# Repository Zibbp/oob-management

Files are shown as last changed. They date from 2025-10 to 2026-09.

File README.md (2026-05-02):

# Out-of-Band Management

## Version 2

See the `v2/` directory for the second version of this project. It replaces the esp32 with a Raspberry PI Pico (rp2040) with a W5500 for Ethernet.

## Story

I do not use any enterprise servers in my homelab, instead primarly consumer parts. Rarely do any consumer or prosumer boards have OOB/IPMI except for some overpriced Asrock boards, so I have no true out-of-band management like IPMI/ILO/etc. I do have an IP-KVM which provides video, HID, and ATX power control for a *single* computer. I need this for many computers, which sent me down the rabbit hole of designing this.

I like my IP-KVM (NanoKVM, though any will work) and wanted to expand this to multiple devices. I researched HDMI KVMs to expand the number of video and HID inputs to 4. The [pikvm docs](https://docs.pikvm.org/multiport/) list a few examples for KVMs. With that information I went to AliExpress and bought the [cheapest 4-port one I could find](https://www.aliexpress.us/item/3256805792824650.html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). Smaller 2-port HDMI KVMs can switch their inputs by pulling a pin to ground. I thought this 4-port version would be the same thing, but I was incorrect. This 4-port KVM uses serial to switch inputs, this will make integration even easier.

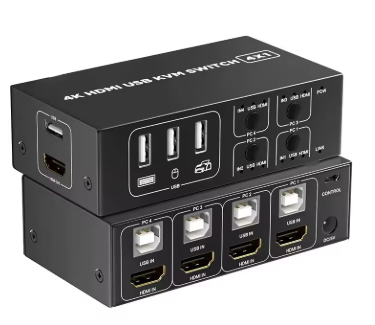
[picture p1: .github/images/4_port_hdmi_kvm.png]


My NanoKVM exposes two UART pins which works pefectly for this. By setting up a serial connection in Python and sending the following string the KVM will switch inputs.

```
G01gA // port 1
G02gA // port 2
G03gA // port 3
G04gA // port 4
```

This solves expanding HID and video to 4 device but I'm still missing power controls such as the power button, reset button, and power LED. I probably could've gotten away with using wake-on-lan packets to power on devices, but as a System Administrator having full remote power control of my servers is a necessity.

## Custom PCBs

This is my first time using KiCad and designing PCBs/schematics/components so there are likely some things wrong. It works for me and I am happy with the results.

### Bravo Board

I took inspritation from the "NanoKVM-B" board which sits inside the computer case and connects to the Motherboard pins *and* the Case wires and designed my own in KiCad. The board I call "Bravo board" sits in the computer case as well. It uses two solid state relays and one optocoupler for the power and reset button and sensing the power LED status respectively. The Bravo board uses a standard RJ45 cable to connect back to the "Alpha board".

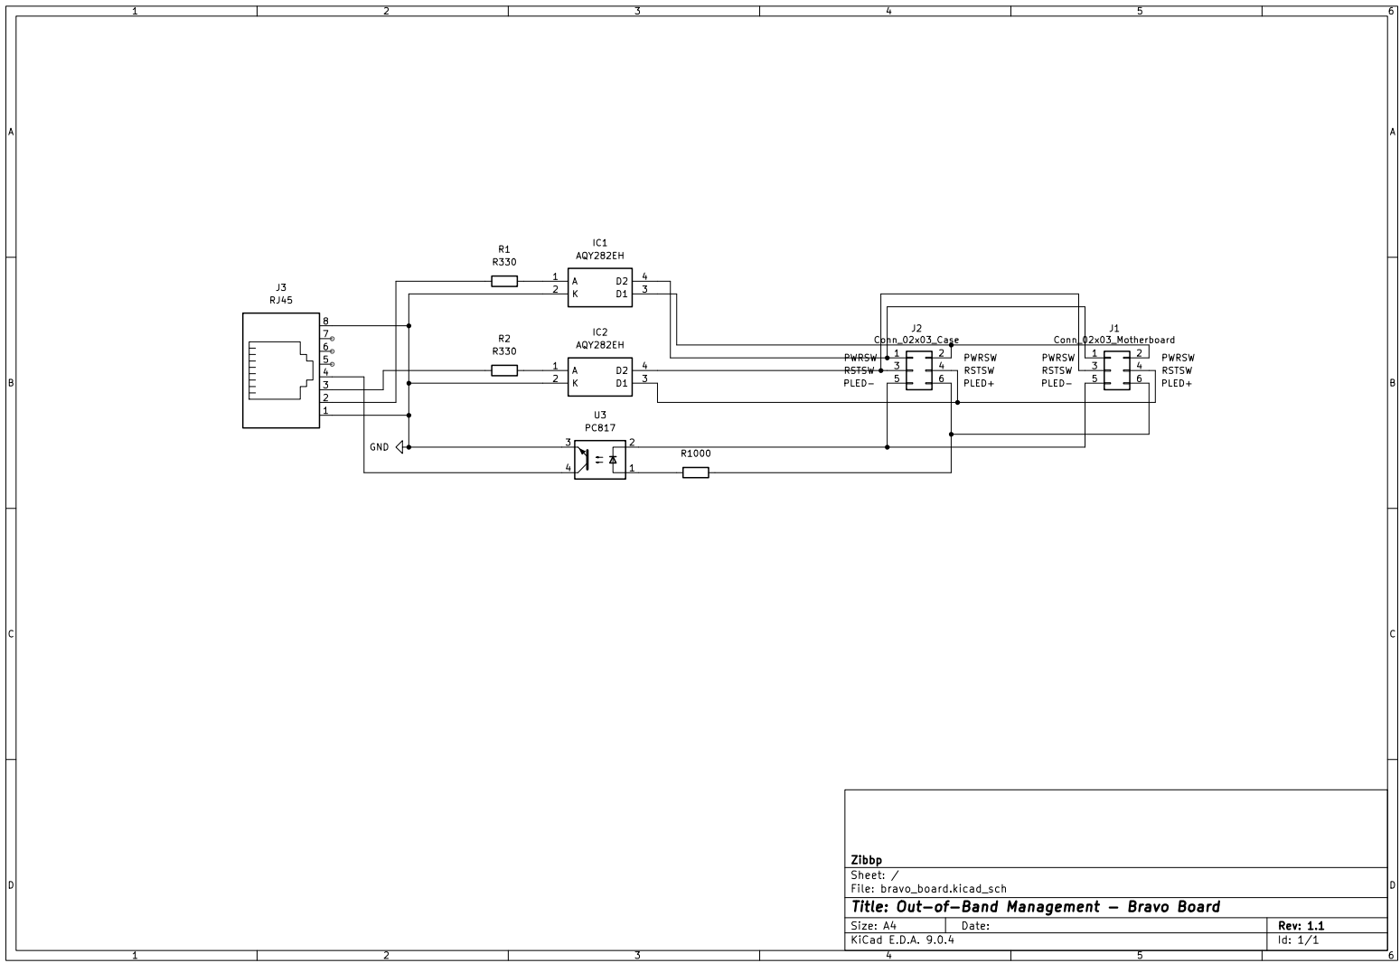
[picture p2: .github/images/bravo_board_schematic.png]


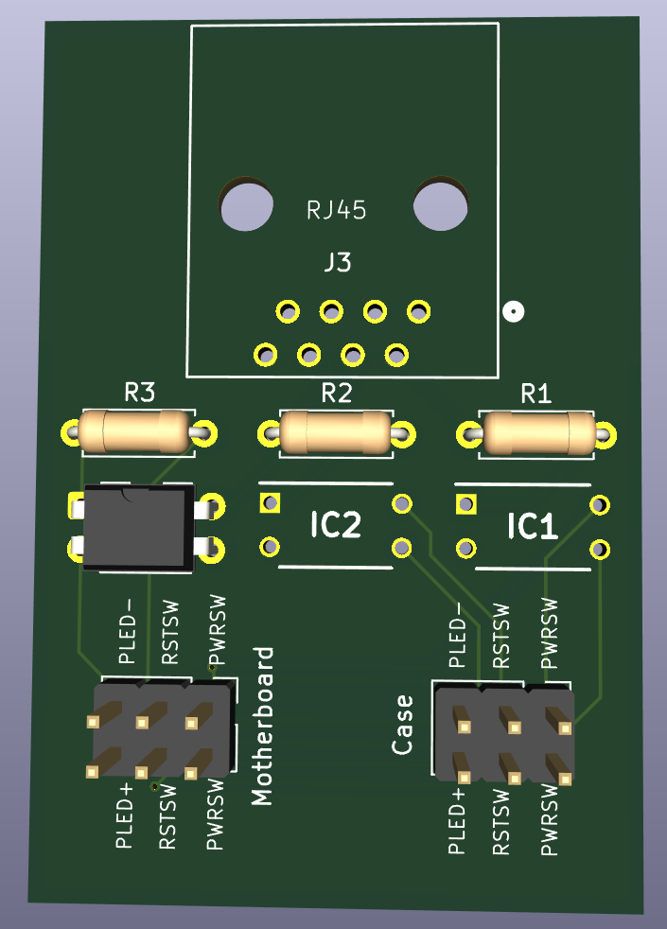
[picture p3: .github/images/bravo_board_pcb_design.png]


### Alpha Board

The "Alpha board" connects to four Bravo boards to control four computers over a standard ethernet cable. It uses a ESP32-C3 as the microcontroller and a GPIO expander. On the board are some status LEDs and two USB connectors for connecting to the HDMI-KVM (to switch video inputs) and optionally for controlling the Alpha board over a serial connection.

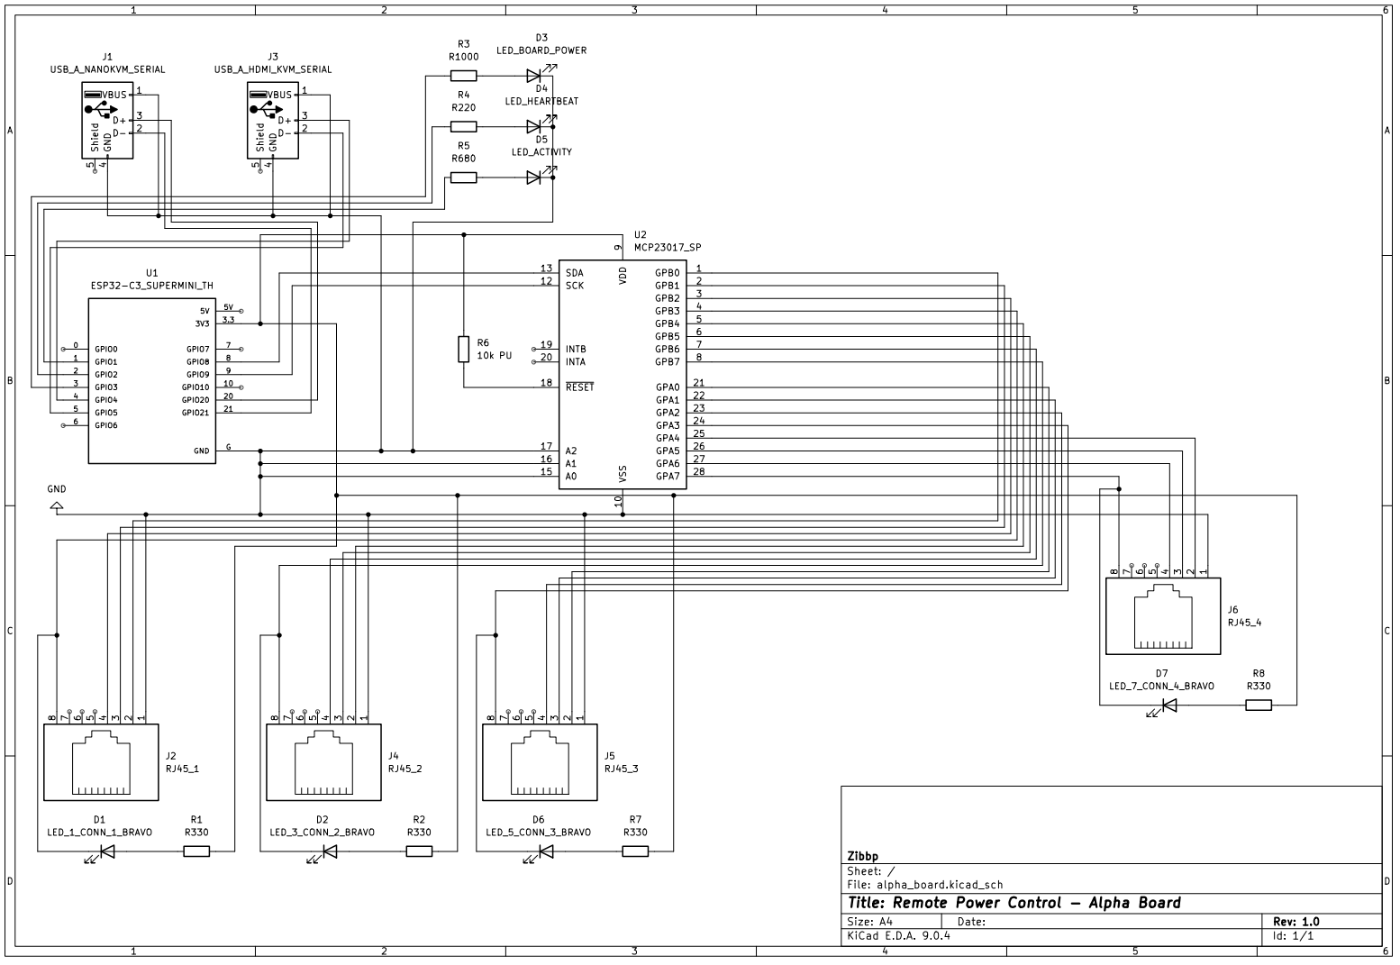
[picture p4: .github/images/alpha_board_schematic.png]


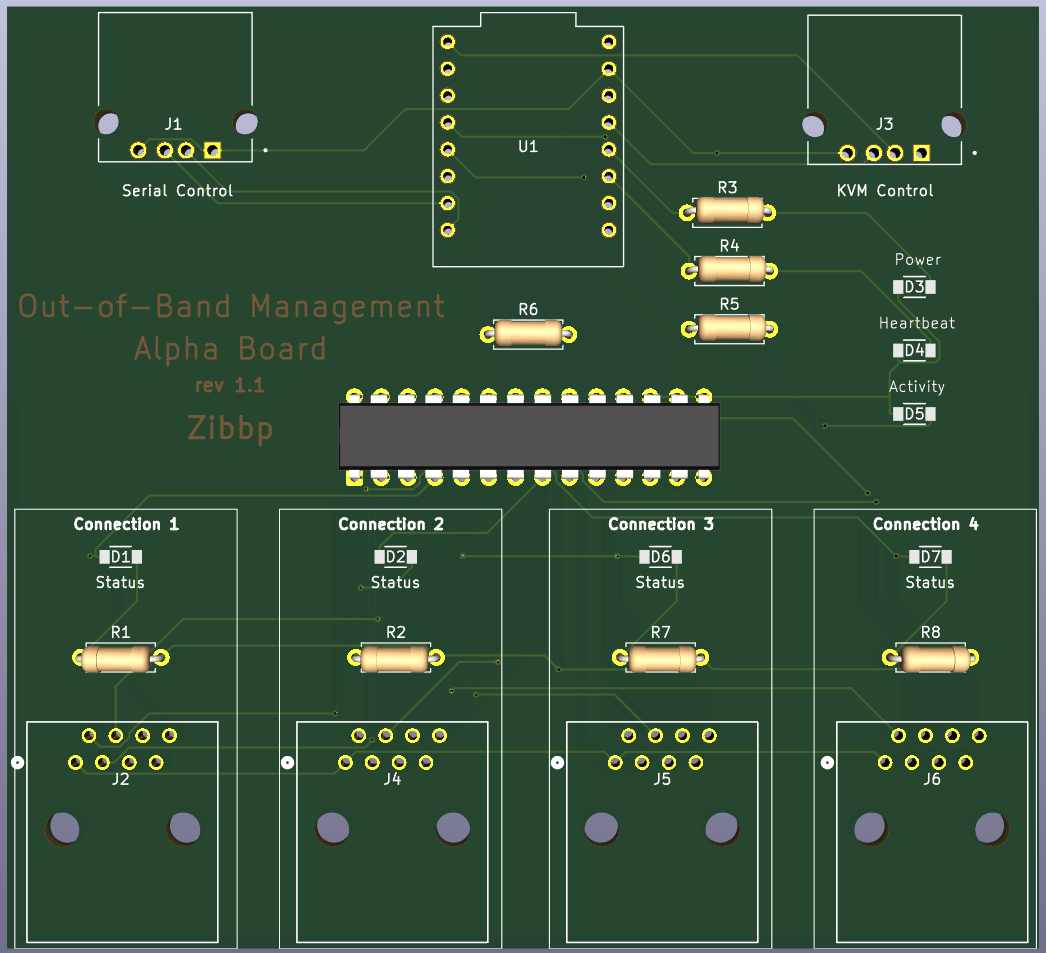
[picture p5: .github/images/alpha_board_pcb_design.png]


## Connecting Everything

This is how the complement OOB Management solution is wired.

Drawing of how the Alpha board connects to Bravo boards.

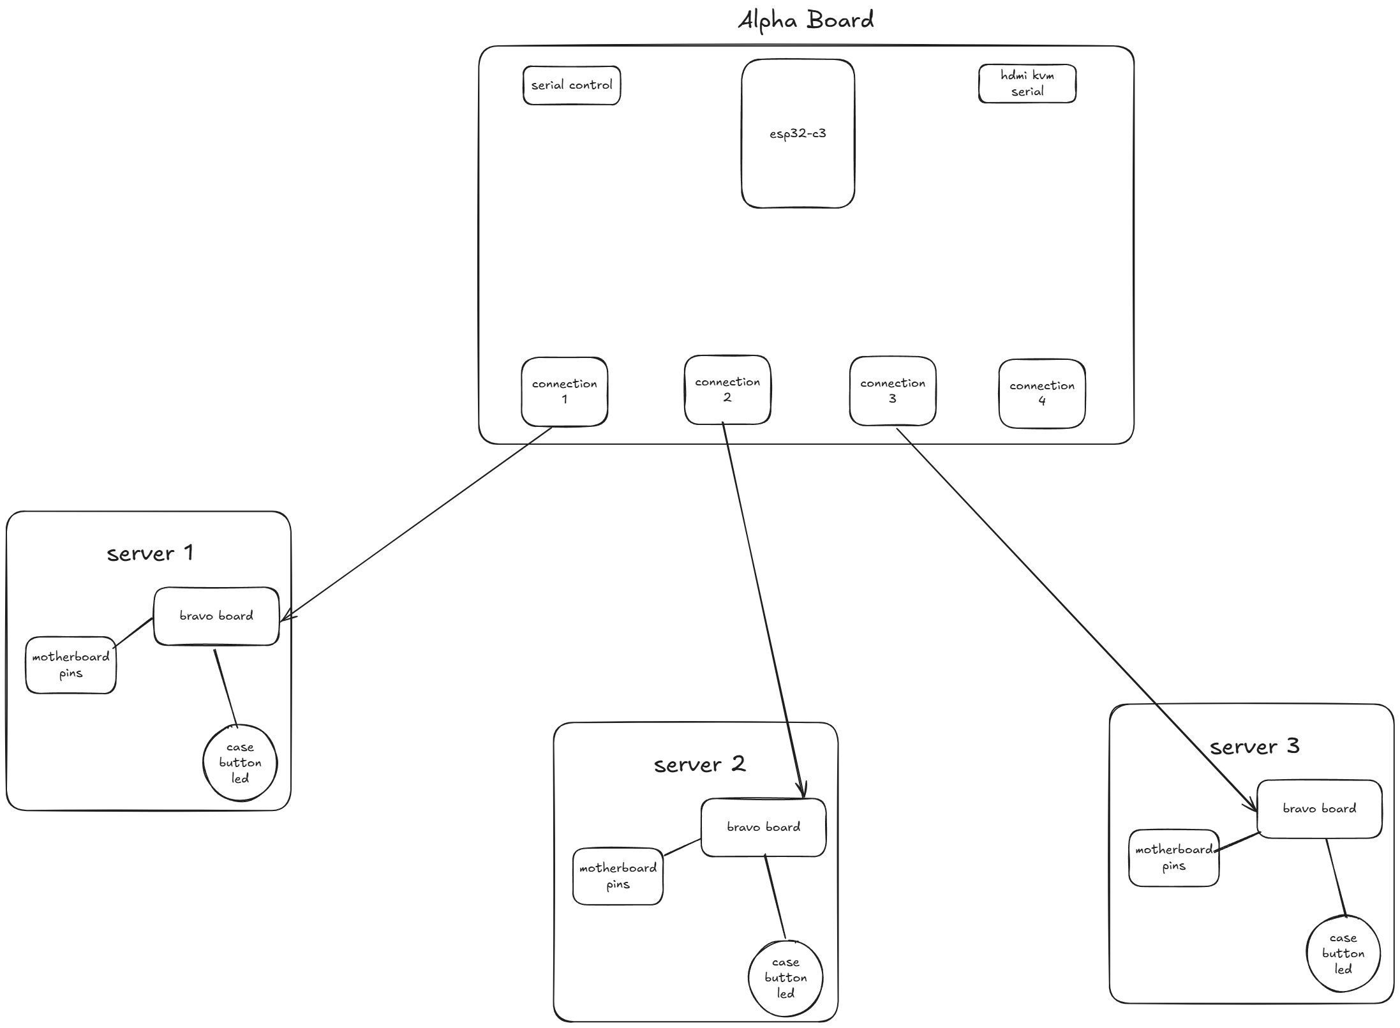
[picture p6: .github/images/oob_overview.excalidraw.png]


Drawing of the entire Out-of-Band Management wiring and setup.

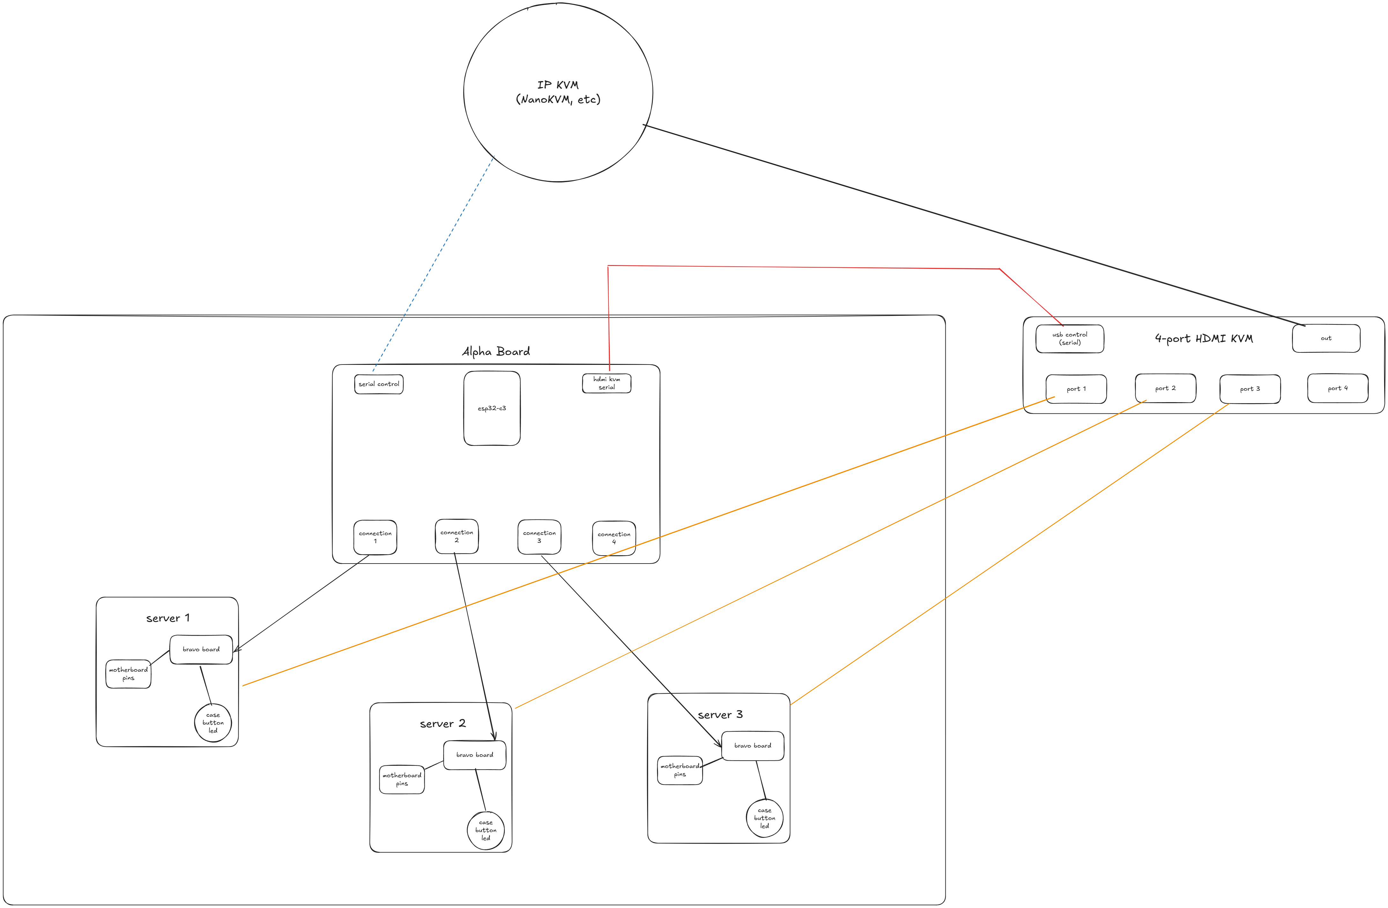
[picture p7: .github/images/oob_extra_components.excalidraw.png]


## Software

[Micropython](https://micropython.org/) is used on the ESP32-C3 to control everything.

Notable features:

- AP fallback / AP for initial WiFi setup
  - The "HeartBeat" LED will flash fast if WiFi is not configured for easy debugging
- Web UI for controlling logic
- HTTP API
- Persistent storage using ESP Non-Volatile storage for WiFi credentials and labels
- *Future* Serial API
  - A future update allowing the IP-KVM to control the Alpha board via a serial connection (or any device)
  - The WiFi WebUI/API works great for me right now though a more stable serial connection would be nice
- Activity LED that flashes when a request is processed
- Bravo connection status LEDs

Web UI image:

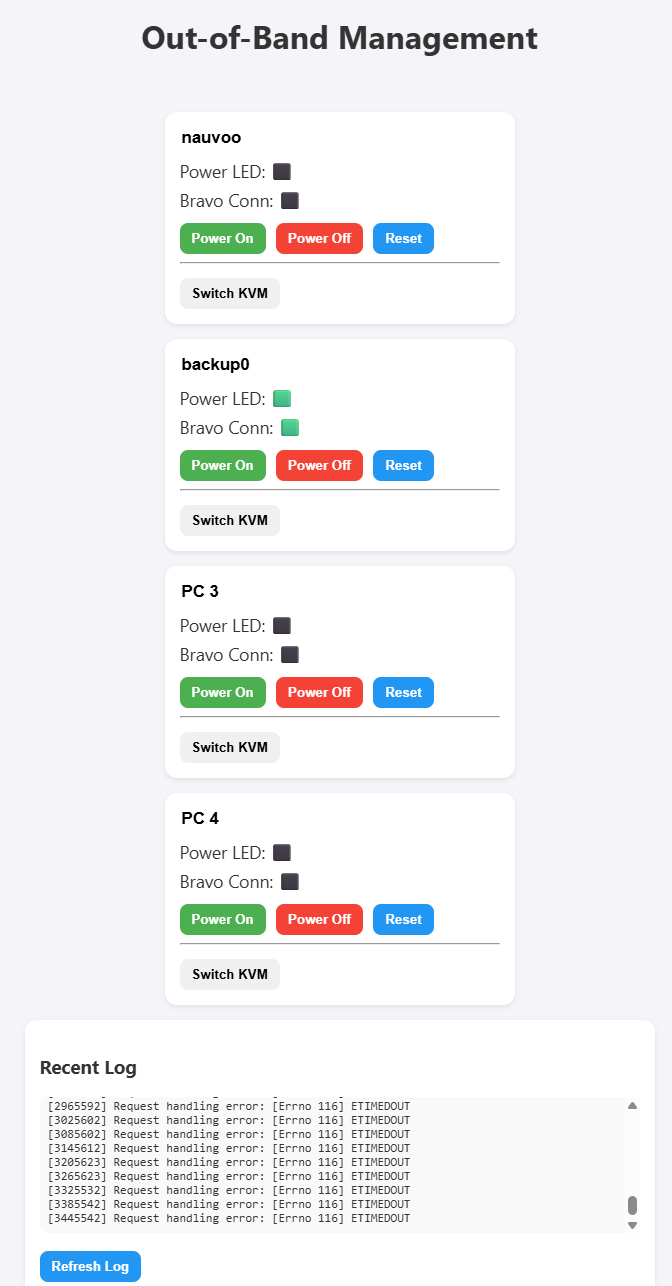
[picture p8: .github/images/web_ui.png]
Web UI


## ESP32-C3 Setup

- Install micropython on the esp32-c3
- Upload the code
  - Look at the `Makefile` for commands or run `make upload`
  - The esp32-c3 needs to be wired up to the GPIO expander for the code to run
- Connect to the Access Point it creates and setup WiFi
  - Name: `OOB-Setup-XXXX`
  - Password: `oobsetup1`
  - Web page: `192.168.4.1`
- Basic authentication
  - Default username and password is `oob`

## Summary

As an introduction into PCBs and KiCad this has been a fantastic project solving a real need. I connect the Bravo board to the computer along with an HDMI and USB cable to the HDMI KVM and I get full control of the computer, similar to IPMI/ILO. 

### Future Improvements

If I ever do a new revision I would likely make the following changes

- Use a microcontroller with ethernet or a W5500 PHY SPI interface
- Make a PCIE slot/mountable version of the Bravo board
  - The RJ45 connector might be too wide/tall

## Parts List

- ESP32-C3 (Supermini)
- SSR Relay (AQY282EH)
- Optoisolator (PC817X2NSZ9F)
- 6POS 2.54MM Pins (Digikey: 2057-PH2-06-UA-ND)
- LED RED Clear 1206 (Digikey: 160-1405-1-ND)
- LED RED Amber 1206 (Digikey: 160-1166-1-ND)
- LED Green Amber 1206 (Digikey: 160-1169-1-ND)
- LED Blue Amber 1206 (Digikey: 160-1643-1-ND)
- USB Type-A RCPT (Digikey: ED2989-ND))
- IC XPNDR 1.7MHZ I2C 28SDIP (Digikey: MCP23017-E/SP-ND)
- MODULAR JACK RJ45 8P8C (Digikey: 2057-MTJ-881X1-ND)
- The various resistors

## Finished Results

After waiting some time for the PCBs and components to arrive, it's complete! Using through-hole components made soldering easy. The small surface mount LEDs were a bit difficult to get soldered on. Here are some images of the Alpha and Bravo boards.

Complete Alpha board and four Bravo boards.

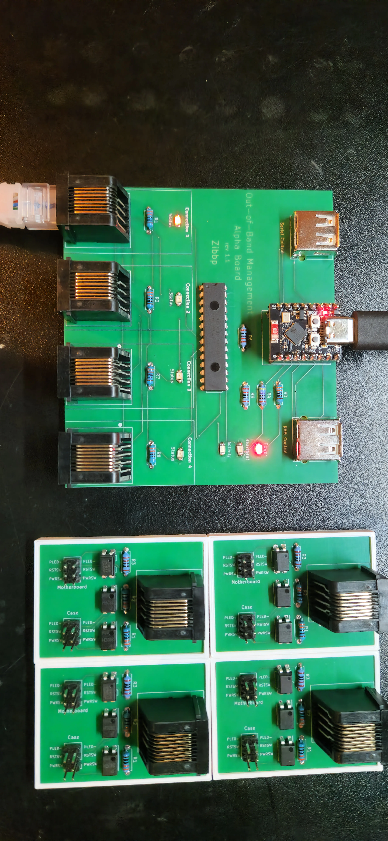
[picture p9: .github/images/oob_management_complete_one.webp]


Bravo board.

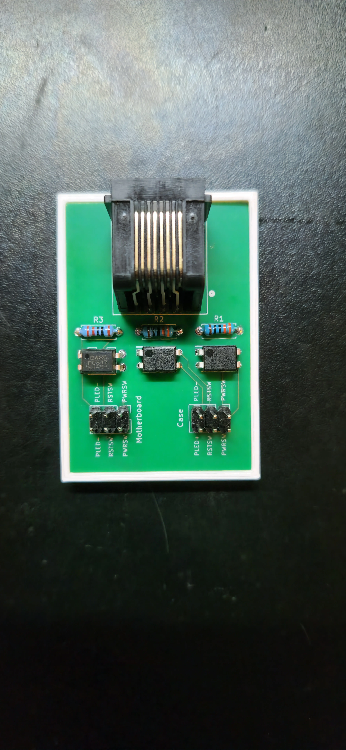
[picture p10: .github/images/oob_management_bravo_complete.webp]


3D printed 10" tiny rack tray for the Alpha board.

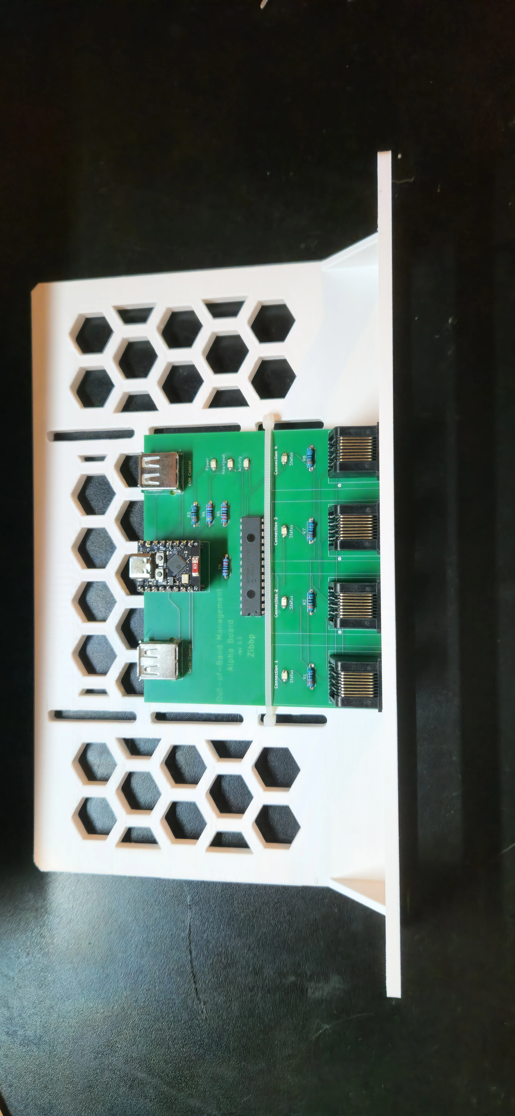
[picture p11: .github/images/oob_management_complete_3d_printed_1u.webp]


Setting up the Bravo board in a computer.

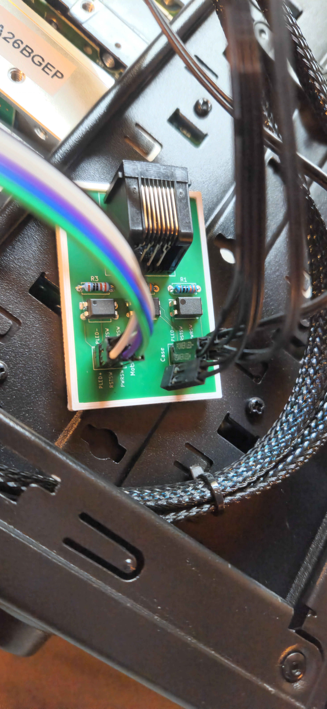
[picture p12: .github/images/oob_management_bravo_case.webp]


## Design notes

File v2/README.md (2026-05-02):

# Version 2

Uses a RPI Pico (rp2040) + a W5500 ethernet over SPI.

## Upload Python code to Raspberry Pi Pico

Use mpremote to deploy code:

1. Upload file:
   mpremote connect auto fs cp main.py :

2. Reset device:
   mpremote connect auto reset

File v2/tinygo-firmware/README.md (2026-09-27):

# oob-firmware

Out-of-band ATX power management for 4 PCs, running on a Raspberry Pi Pico (RP2040) with W5500 Ethernet. TinyGo port of the MicroPython setup in `old/`.

Web UI for power/reset/force-off per PC, KVM switching, editable labels, login change, and an activity log. No OTA — firmware updates are USB-only.

## Hardware

| Part | Connection |
| ---- | --- |
| W5500 Ethernet | SPI0: SCK GP18, MOSI GP19, MISO GP16, CS GP17, RST GP20 |
| MCP23017 I/O expander | I2C1: SDA GP2, SCL GP3, addr `0x20`, 100 kHz |
| KVM switch (TX only) | GP5, 19200 baud 8N1, sends `G0XdA` |
| External device console | UART0: TX GP0, RX GP1, 115200 baud 8N1 (`SERIAL_*` in `config.go`) |
| Controller LED | GP6 + Pico onboard LED (solid when ready, blink while waiting for network) |

Each PC uses 4 MCP23017 pins: power-switch pulse (out), reset-switch pulse (out), motherboard power-LED sense (in, active-low), aux sense (in, active-low).

| PC | Bank | Power | Reset | LED | Aux |
| -- | ---- | ----- | ----- | --- | --- |
| 1 | A | 0 | 1 | 2 | 3 |
| 2 | A | 4 | 5 | 6 | 7 |
| 3 | B | 0 | 1 | 2 | 3 |
| 4 | B | 4 | 5 | 6 | 7 |

Pulse lengths: power 1.0 s, reset 0.7 s, force-off (hold) 5 s. Pin map and timings live in `config.go`.

## Network

- DHCP only (`hostname oob-pico`). No link/lease → both LEDs blink and it retries forever. There is no static-IP fallback.
- MAC is locally administered, derived from the flash ID: `02:4F:4F:42:XX:XX`.
- HTTP on port 80. Basic auth (default `oob` / `oob`), changeable in the Web UI; credentials and labels persist across reboots *and* USB reflashes (dedicated flash sector).

## Web UI

`http://<dhcp-ip>/` (try `http://oob-pico/` if your LAN resolves hostnames). Per-PC cards with live power/aux state, Power / Reset / Hold-5s / KVM buttons, click-to-rename labels, activity log, access settings. Tick the `serial` checkbox in the header to show the external-device console (output view, send box, clear).

API (all except `/health` need Basic auth):
| Endpoint | Method | Notes |
| --- | --- | ----- |
| `/` | GET | UI |
| `/status` | GET | JSON: version, ip, link, per-PC state |
| `/health` | GET | `{"ok":true}` — no auth |
| `/log` | GET | plain-text ring (80 entries) |
| `/action` | POST | `pc=1..4`, `action=power\|reset\|force_off` (`poweron`/`poweroff` aliases) |
| `/kvm` | POST | `port=1..4` |
| `/label` (`/setlabel`) | POST | `pc=1..4`, `name=≤32 chars` |
| `/auth` | POST | `user=≤32 chars`, `pass=≤64 chars` |
| `/serial` | GET | buffered external-device output, plain text |
| `/serial/send` | POST | `text=…` writes to the device UART |
| `/serial/clear` | POST | clears the serial buffer |

## Layout

```
main.go      boot + supervise network → serve forever
config.go    pins, PC table, timings, defaults
netbring.go  W5500 init + minimal DHCP client
mcp.go       MCP23017 outputs/inputs, ATX actions
kvm.go       bit-banged 19200 TX
serial.go    UART0 device console (RX ring + TX)
store.go     labels + credentials in flash
server.go    self-healing HTTP server (see below)
web.go       routes + auth
ui.html      embedded UI (//go:embed)
```

Upstream deps only: `tinygo.org/x/drivers` (w5500, mcp23017) plus `github.com/tinygo-org/pio` for the KVM UART (bit-exact port of the old MicroPython PIO program). The stock `net/http` server dies permanently on transient W5500 accept errors, so `server.go` runs its own accept loop that re-creates a wedged listener instead. The W5500 accept path has a millisecond deaf window per connection, so the UI staggers polls and retries once silently — actions never retry (no double power-presses).

## Build & flash

Requirements: TinyGo ≥ 0.42.

```sh
# inspect
tinygo build -target pico -o firmware.elf .

# flash over USB (Pico in BOOTSEL: hold BOOTSEL, tap RESET / replug)
tinygo flash -target pico .

# or copy the UF2 manually
tinygo build -target pico -o firmware.uf2 .
# then drop firmware.uf2 onto the RPI-RP2 mass-storage drive
```

Serial log (115200 baud) shows DHCP and HTTP progress, e.g.:

```
[2720] link up: 100Mbps Full Duplex
[2727] net: ip=197.100.1.189 mask=255.255.255.0 gw=197.100.1.1
[2728] listening on http://197.100.1.189:80/
```

Note: `tinygo flash` on a running device needs serial-port access to reset it into BOOTSEL; without permission, enter BOOTSEL manually.

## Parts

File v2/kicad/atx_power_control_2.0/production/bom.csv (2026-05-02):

Designator | Footprint | Quantity | Value | LCSC Part #
A1 | RaspberryPi_Pico_Common_Unspecified | 1 | RaspberryPi_Pico
D1 | LED_LTST-C150GKT_LTO | 1 | LED_BOARD_POWER
D2 | LED_LTST-C150GKT_LTO | 1 | LED_CONN_4_BRAVO
D3 | LED_LTST-C150GKT_LTO | 1 | LED_CONN_3_BRAVO
D4 | LED_LTST-C150GKT_LTO | 1 | LED_CONN_2_BRAVO
D5 | LED_LTST-C150GKT_LTO | 1 | LED_CONN_1_BRAVO
IC1 | USRES1 | 1 | USR-ES1
J1 | OST_USB-A1HSW6 | 1 | USB_A_HDMI_KVM_SERIAL
J2 | MTJ88ARX1FSMLH | 1 | RJ45_CONN1
J3 | MTJ88ARX1FSMLH | 1 | RJ45_CONN2
J4 | MTJ88ARX1FSMLH | 1 | RJ45_CONN3
J5 | MTJ88ARX1FSMLH | 1 | RJ45_CONN4
R1 | R_Axial_DIN0207_L6.3mm_D2.5mm_P7.62mm_Horizontal | 1 | R-10K PU
R2 | R_Axial_DIN0207_L6.3mm_D2.5mm_P7.62mm_Horizontal | 1 | R330
R3 | R_Axial_DIN0207_L6.3mm_D2.5mm_P7.62mm_Horizontal | 1 | R330_CONN4
R4 | R_Axial_DIN0207_L6.3mm_D2.5mm_P7.62mm_Horizontal | 1 | R330_CONN3
R5 | R_Axial_DIN0207_L6.3mm_D2.5mm_P7.62mm_Horizontal | 1 | R330_CONN2
R6 | R_Axial_DIN0207_L6.3mm_D2.5mm_P7.62mm_Horizontal | 1 | R330_CONN1
U2 | DIP-28_W7.62mm | 1 | MCP23017x-x-SP

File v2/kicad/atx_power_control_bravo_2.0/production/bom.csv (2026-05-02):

Designator | Footprint | Quantity | Value | LCSC Part #
J1 | MTJ88ARX1FSMLH | 1 | MTJ-88ARX1-FSM-LH
J2 | PinHeader_2x03_P2.54mm_Horizontal | 1 | Conn_02x03_CASE
J3 | PinHeader_2x03_P2.54mm_Horizontal | 1 | Conn_02x03_Odd_MOTHERBOARD
R1, R2 | R_Axial_DIN0207_L6.3mm_D2.5mm_P7.62mm_Horizontal | 2 | R330
R3 | R_Axial_DIN0207_L6.3mm_D2.5mm_P7.62mm_Horizontal | 1 | R1000
U1, U2 | DIP-4_W7.62mm | 2 | AQY282EH
U3 | DIP-4_W7.62mm | 1 | PC817

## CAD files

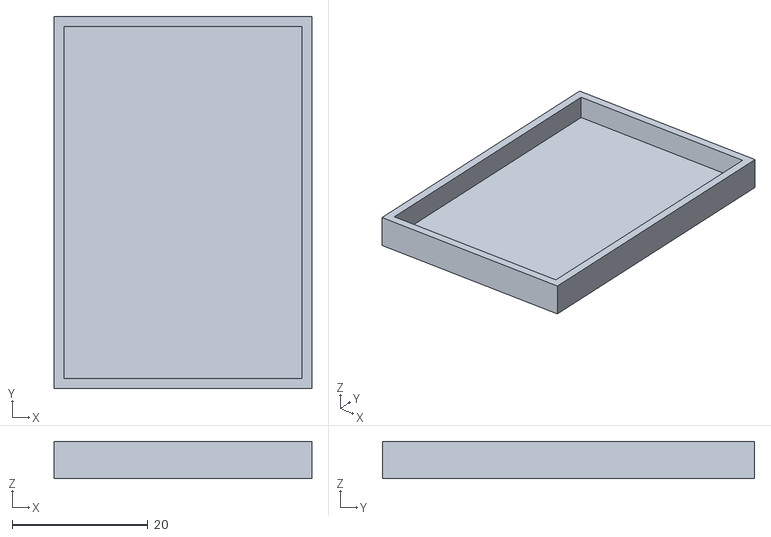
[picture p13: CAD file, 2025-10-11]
bravo_housing.stl
38.0 x 54.8 x 5.50

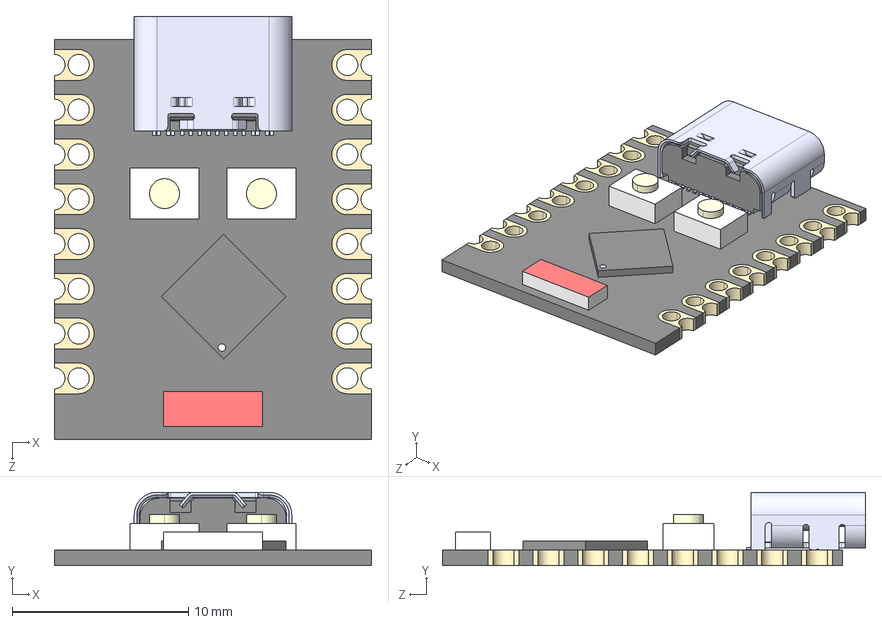
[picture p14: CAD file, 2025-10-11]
kicad/custom_symbols/ESP32-C3_SUPERMINI_TH/ESP32-C3_SUPERMINI_TH.step
18.0 x 4.16 x 24.0 mm
Board c3mini
USB C
components (other)^ESP32-C3 SuperMini

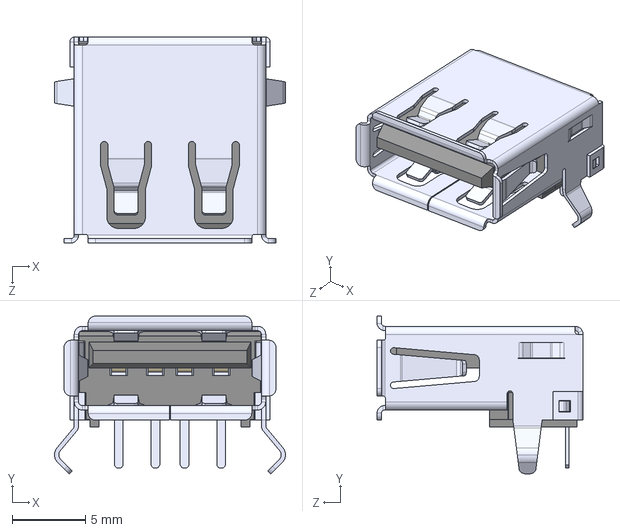
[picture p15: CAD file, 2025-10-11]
kicad/custom_symbols/USB_A1HSW6/USB-A1HSW6.step
15.8 x 10.8 x 14.1 mm

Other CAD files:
v2/pcie_board_with_full_height_bracket.blend
v2/pcie_board_with_full_height_bracket_spec_corrected.blend

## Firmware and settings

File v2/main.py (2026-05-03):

import gc
import os
import socket
import time

try:
    import ujson as json
except ImportError:
    import json

try:
    import ubinascii as binascii
except ImportError:
    import binascii

import network
import machine
from machine import I2C, Pin, SPI

try:
    from rp2 import PIO, StateMachine, asm_pio
except ImportError:
    PIO = None
    StateMachine = None
    asm_pio = None


APP_NAME = "OOB Management"
APP_VERSION = "2.0.0-pico"
HOSTNAME = "oob-pico"
HTTP_PORT = 80
DHCP_TIMEOUT_SECONDS = 30
HTTP_CLIENT_TIMEOUT_SECONDS = 2
HTTP_ACCEPT_TIMEOUT_SECONDS = 1
HTTP_MAX_REQUEST_BYTES = 8192

OTA_ENABLED = True
OTA_MAX_BYTES = 96 * 1024
OTA_MAIN_FILE = "main.py"
OTA_UPLOAD_FILE = "main.py.upload"
OTA_BACKUP_FILE = "main.py.bak"
OTA_PENDING_FILE = "ota_pending.json"
OTA_BOOTING_FILE = "ota_booting"

# Set AUTH_ENABLED to False if this controller lives on a fully isolated network.
AUTH_ENABLED = True
AUTH_USER = "oob"
AUTH_PASS = "oob"

# Raspberry Pi Pico to W5500 / USR-ES1 wiring.
W5500_SPI_ID = 0
W5500_PIN_SCK = 18
W5500_PIN_MOSI = 19
W5500_PIN_MISO = 16
W5500_PIN_CS = 17
W5500_PIN_RST = 20

# Raspberry Pi Pico to MCP23017 wiring.
MCP_I2C_ID = 1
MCP_PIN_SDA = 2
MCP_PIN_SCL = 3
MCP_ADDR = 0x20
MCP_I2C_FREQ = 100000

# Optional transmit-only serial/KVM link using RP2040 PIO.
KVM_PIO_SM_ID = 0
KVM_UART_BAUD = 19200
KVM_PIN_TX = 5

# Controller status LED.
POWER_LED_PIN = 6

# MCP23017 register map.
IODIRA = 0x00
IODIRB = 0x01
GPPUA = 0x0C
GPPUB = 0x0D
GPIOA = 0x12
GPIOB = 0x13
OLATA = 0x14
OLATB = 0x15

# Each RJ45 group uses four MCP pins in this order:
# port 2 = ATX power switch pulse
# port 3 = ATX reset switch pulse
# port 4 = motherboard power LED sense
# port 8 = spare/aux sense
#
# Adjust this table if the harness order changes.
PCS = (
    {
        "id": 1,
        "name": "PC 1",
        "bank": "A",
        "power": 0,
        "reset": 1,
        "power_led": 2,
        "aux": 3,
    },
    {
        "id": 2,
        "name": "PC 2",
        "bank": "A",
        "power": 4,
        "reset": 5,
        "power_led": 6,
        "aux": 7,
    },
    {
        "id": 3,
        "name": "PC 3",
        "bank": "B",
        "power": 0,
        "reset": 1,
        "power_led": 2,
        "aux": 3,
    },
    {
        "id": 4,
        "name": "PC 4",
        "bank": "B",
        "power": 4,
        "reset": 5,
        "power_led": 6,
        "aux": 7,
    },
)

ACTIVE_LOW_SENSE = True
POWER_PULSE_SECONDS = 1.0
RESET_PULSE_SECONDS = 0.7
FORCE_OFF_SECONDS = 5.0
LABELS_FILE = "labels.json"
LOG_MAX_ENTRIES = 80
LOG_MAX_LINE_CHARS = 160


if asm_pio:

    @asm_pio(
        sideset_init=PIO.OUT_HIGH, out_init=PIO.OUT_HIGH, out_shiftdir=PIO.SHIFT_RIGHT
    )
    def pio_uart_tx():
        pull()
        set(x, 7).side(0)[7]
        label("bitloop")
        out(pins, 1)[6]
        jmp(x_dec, "bitloop")
        nop().side(1)[6]

else:
    pio_uart_tx = None


log_lines = []
labels = {}
nic = None
try:
    OTA_WDT
except NameError:
    OTA_WDT = None
controller_led = Pin(POWER_LED_PIN, Pin.OUT)
controller_led.on()


def feed_watchdog():
    if OTA_WDT:
        try:
            OTA_WDT.feed()
        except Exception:
            pass


def sleep_with_watchdog(seconds):
    milliseconds = int(seconds * 1000)
    if milliseconds <= 0:
        feed_watchdog()
        return

    deadline = time.ticks_add(time.ticks_ms(), milliseconds)
    while time.ticks_diff(deadline, time.ticks_ms()) > 0:
        feed_watchdog()
        remaining = time.ticks_diff(deadline, time.ticks_ms())
        time.sleep_ms(min(1000, max(1, remaining)))
    feed_watchdog()


def file_exists(path):
    try:
        os.stat(path)
        return True
    except OSError:
        return False


def remove_file(path):
    try:
        os.remove(path)
    except OSError:
        pass


def log(message):
    message = str(message)
    if len(message) > LOG_MAX_LINE_CHARS:
        message = message[: LOG_MAX_LINE_CHARS - 3] + "..."
    line = "[{}] {}".format(time.ticks_ms(), message)
    print(line)
    log_lines.append(line)
    while len(log_lines) > LOG_MAX_ENTRIES:
        log_lines.pop(0)


def log_text():
    if not log_lines:
        return ""
    return "\n".join(log_lines) + "\n"


def sync_filesystem():
    try:
        os.sync()
    except Exception:
        pass


def get_ipv4_config(iface):
    try:
        ip, subnet = iface.ipconfig("addr4")
        gateway = iface.ipconfig("gw4")
        try:
            dns = network.ipconfig("dns")
        except Exception:
            dns = "unknown"
        return ip, subnet, gateway, dns
    except Exception:
        return iface.ifconfig()


def has_ipv4_address(iface):
    ip, _, _, _ = get_ipv4_config(iface)
    return ip not in ("0.0.0.0", None, "")


def connect_w5500_dhcp():
    feed_watchdog()
    log("Starting W5500 Ethernet")
    spi = SPI(
        W5500_SPI_ID,
        baudrate=2_000_000,
        polarity=0,
        phase=0,
        sck=Pin(W5500_PIN_SCK),
        mosi=Pin(W5500_PIN_MOSI),
        miso=Pin(W5500_PIN_MISO),
    )

    iface = network.WIZNET5K(spi, Pin(W5500_PIN_CS), Pin(W5500_PIN_RST))
    feed_watchdog()

    try:
        network.hostname(HOSTNAME)
    except Exception:
        pass

    iface.active(True)
    feed_watchdog()

    try:
        iface.ipconfig(dhcp4=True)
        log("DHCP requested")
    except Exception:
        log("Waiting for default DHCP")

    deadline = time.time() + DHCP_TIMEOUT_SECONDS
    while time.time() < deadline:
        feed_watchdog()
        if iface.isconnected() and has_ipv4_address(iface):
            ip, subnet, gateway, dns = get_ipv4_config(iface)
            log(
                "Ethernet connected: ip={} subnet={} gateway={} dns={}".format(
                    ip, subnet, gateway, dns
                )
            )
            return iface

        log("Waiting for Ethernet link/DHCP")
        sleep_with_watchdog(1)

    log("Ethernet link up: {}".format(iface.isconnected()))
    log("Network config: {}".format(get_ipv4_config(iface)))
    raise RuntimeError("Timed out waiting for Ethernet DHCP lease")


class MCP23017:
    def __init__(self, i2c, address, bus_name):
        self.i2c = i2c
        self.address = address
        self.bus_name = bus_name
        self.output_latch = {"A": 0, "B": 0}

    def write_reg(self, reg, value):
        self.i2c.writeto_mem(self.address, reg, bytes([value & 0xFF]))

    def read_reg(self, reg):
        return self.i2c.readfrom_mem(self.address, reg, 1)[0]

    def begin(self):
        feed_watchdog()
        found = self.i2c.scan()
        feed_watchdog()
        if self.address not in found:
            mcp_addresses = []
            for address in found:
                if MCP_ADDR_MIN <= address <= MCP_ADDR_MAX:
                    mcp_addresses.append(address)

            if mcp_addresses:
                self.address = mcp_addresses[0]
                log(
                    "MCP23017 expected at 0x{:02X}, using detected address 0x{:02X}".format(
                        MCP_ADDR, self.address
                    )
                )
            else:
                raise RuntimeError(
                    "MCP23017 not found at 0x{:02X} on {}; scan={}. "
                    "Check VDD/VSS, common ground, SDA/SCL wiring, pull-ups, RESET high, "
                    "and A0/A1/A2 address pins.".format(
                        self.address, self.bus_name, found
                    )
                )

        input_mask_a = 0
        input_mask_b = 0
        for pc in PCS:
            mask = (1 << pc["power_led"]) | (1 << pc["aux"])
            if pc["bank"] == "A":
                input_mask_a |= mask
            else:
                input_mask_b |= mask

        self.write_reg(OLATA, 0x00)
        feed_watchdog()
        self.write_reg(OLATB, 0x00)
        self.write_reg(IODIRA, input_mask_a)
        self.write_reg(IODIRB, input_mask_b)
        self.write_reg(GPPUA, input_mask_a)
        self.write_reg(GPPUB, input_mask_b)
        feed_watchdog()
        log(
            "MCP23017 ready: IODIRA=0x{:02X} IODIRB=0x{:02X}".format(
                input_mask_a, input_mask_b
            )
        )

    def gpio_reg(self, bank):
        return GPIOA if bank == "A" else GPIOB

    def olat_reg(self, bank):
        return OLATA if bank == "A" else OLATB

    def read_pin(self, bank, bit):
        value = self.read_reg(self.gpio_reg(bank))
        raw = (value >> bit) & 1
        if ACTIVE_LOW_SENSE:
            return 1 if raw == 0 else 0
        return raw

    def set_output(self, bank, bit, enabled):
        mask = 1 << bit
        if enabled:
            self.output_latch[bank] |= mask
        else:
            self.output_latch[bank] &= ~mask
        self.write_reg(self.olat_reg(bank), self.output_latch[bank])

    def pulse(self, bank, bit, seconds):
        feed_watchdog()
        self.set_output(bank, bit, True)
        sleep_with_watchdog(seconds)
        self.set_output(bank, bit, False)
        feed_watchdog()


def make_mcp():
    feed_watchdog()
    bus_name = "I2C{} SDA=GPIO{} SCL=GPIO{} freq={}".format(
        MCP_I2C_ID, MCP_PIN_SDA, MCP_PIN_SCL, MCP_I2C_FREQ
    )
    i2c = I2C(MCP_I2C_ID, scl=Pin(MCP_PIN_SCL), sda=Pin(MCP_PIN_SDA), freq=MCP_I2C_FREQ)
    expander = MCP23017(i2c, MCP_ADDR, bus_name)
    expander.begin()
    feed_watchdog()
    return expander


class PioUartTx:
    def __init__(self, state_machine_id, pin, baudrate):
        if not (PIO and StateMachine and pio_uart_tx):
            raise RuntimeError("RP2040 PIO is not available")
        tx_pin = Pin(pin)
        self.sm = StateMachine(
            state_machine_id,
            pio_uart_tx,
            freq=8 * baudrate,
            sideset_base=tx_pin,
            out_base=tx_pin,
        )
        self.sm.active(1)

    def write(self, data):
        if isinstance(data, str):
            data = data.encode()
        for byte in data:
            self.sm.put(byte)


def make_kvm_uart():
    feed_watchdog()
    try:
        return PioUartTx(KVM_PIO_SM_ID, KVM_PIN_TX, KVM_UART_BAUD)
    except Exception as exc:
        log("KVM UART disabled: {}".format(exc))
        return None


mcp = make_mcp()
kvm_uart = make_kvm_uart()


def load_labels():
    global labels
    labels = {}
    try:
        with open(LABELS_FILE, "r") as f:
            stored = json.loads(f.read())
        for pc in PCS:
            key = str(pc["id"])
            name = stored.get(key, pc["name"])
            labels[pc["id"]] = name[:32] if name else pc["name"]
        log("Loaded labels")
    except Exception:
        for pc in PCS:
            labels[pc["id"]] = pc["name"]


def save_labels():
    data = {}
    for pc_id, name in labels.items():
        data[str(pc_id)] = name
    with open(LABELS_FILE, "w") as f:
        f.write(json.dumps(data))
    sync_filesystem()
    log("Saved labels")


def find_pc(pc_id):
    for pc in PCS:
        if pc["id"] == pc_id:
            return pc
    return None


def pc_status():
    pcs = []
    for pc in PCS:
        power_on = bool(mcp.read_pin(pc["bank"], pc["power_led"]))
        aux_on = bool(mcp.read_pin(pc["bank"], pc["aux"]))
        pcs.append(
            {
                "id": pc["id"],
                "label": labels.get(pc["id"], pc["name"]),
                "power_on": power_on,
                "aux_on": aux_on,
                "bank": pc["bank"],
                "power_bit": pc["power"],
                "reset_bit": pc["reset"],
                "led_bit": pc["power_led"],
                "aux_bit": pc["aux"],
            }
        )
    return pcs


def kvm_switch(port):
    if not (1 <= port <= len(PCS)):
        raise ValueError("Invalid KVM port")
    if not kvm_uart:
        raise RuntimeError("KVM UART is not available")
    kvm_uart.write("G0{}gA".format(port))
    log("KVM switched to port {}".format(port))


def run_action(pc_id, action):
    pc = find_pc(pc_id)
    if not pc:
        raise ValueError("Unknown PC")

    if action == "poweron":
        action = "power"
    elif action == "poweroff":
        action = "force_off"

    if action == "power":
        log("Power pulse for PC {}".format(pc_id))
        mcp.pulse(pc["bank"], pc["power"], POWER_PULSE_SECONDS)
    elif action == "reset":
        log("Reset pulse for PC {}".format(pc_id))
        mcp.pulse(pc["bank"], pc["reset"], RESET_PULSE_SECONDS)
    elif action == "force_off":
        log("Force-off pulse for PC {}".format(pc_id))
        mcp.pulse(pc["bank"], pc["power"], FORCE_OFF_SECONDS)
    else:
        raise ValueError("Unknown action")


def url_unquote(value):
    out = []
    i = 0
    while i < len(value):
        char = value[i]
        if char == "%" and i + 2 < len(value):
            try:
                out.append(chr(int(value[i + 1 : i + 3], 16)))
                i += 3
                continue
            except Exception:
                pass
        out.append(" " if char == "+" else char)
        i += 1
    return "".join(out)


def parse_kv_pairs(value):
    params = {}
    if not value:
        return params
    for item in value.split("&"):
        if not item:
            continue
        if "=" in item:
            key, val = item.split("=", 1)
        else:
            key, val = item, ""
        params[url_unquote(key)] = url_unquote(val)
    return params


def split_path_query(path):
    if "?" not in path:
        return path, {}
    route, query = path.split("?", 1)
    return route, parse_kv_pairs(query)


def parse_content_length(headers):
    try:
        return int(headers.get("content-length", "0") or "0")
    except Exception:
        raise ValueError("Invalid Content-Length")


def read_request_start(client):
    client.settimeout(HTTP_CLIENT_TIMEOUT_SECONDS)
    data = b""
    while b"\r\n\r\n" not in data:
        feed_watchdog()
        chunk = client.recv(1024)
        if not chunk:
            break
        data += chunk
        if len(data) > HTTP_MAX_REQUEST_BYTES:
            raise ValueError("Request headers too large")

    head, _, rest = data.partition(b"\r\n\r\n")
    lines = head.split(b"\r\n")
    if not lines or not lines[0]:
        return "", "", {}, b""

    try:
        method, path, _proto = lines[0].decode().split(" ", 2)
    except Exception:
        return "", "", {}, b""

    headers = {}
    for line in lines[1:]:
        if b":" in line:
            key, value = line.split(b":", 1)
            headers[key.decode().strip().lower()] = value.decode().strip()

    return method, path, headers, rest


def read_request_body(client, headers, initial_body, max_bytes=HTTP_MAX_REQUEST_BYTES):
    length = parse_content_length(headers)
    if length > max_bytes:
        raise ValueError("Request body too large")

    body = initial_body[:length]
    while len(body) < length:
        feed_watchdog()
        chunk = client.recv(min(1024, length - len(body)))
        if not chunk:
            break
        body += chunk

    if len(body) != length:
        raise ValueError("Incomplete request body")

    return body


def stream_request_body_to_file(client, headers, initial_body, path, max_bytes):
    length = parse_content_length(headers)
    if length <= 0:
        raise ValueError("Upload is empty")
    if length > max_bytes:
        raise ValueError("Upload is too large")

    written = 0
    with open(path, "wb") as f:
        if initial_body:
            chunk = initial_body[:length]
            f.write(chunk)
            written += len(chunk)
            feed_watchdog()

        while written < length:
            feed_watchdog()
            chunk = client.recv(min(1024, length - written))
            if not chunk:
                raise ValueError("Upload ended early")
            f.write(chunk)
            written += len(chunk)

    sync_filesystem()
    return written


def validate_ota_upload(path):
    feed_watchdog()
    gc.collect()
    source = None
    code = None
    try:
        with open(path, "r") as f:
            source = f.read()
        feed_watchdog()
        code = compile(source, OTA_MAIN_FILE, "exec")
        feed_watchdog()
    except Exception as exc:
        raise ValueError("Upload validation failed: {}".format(exc))
    finally:
        try:
            del code
        except Exception:
            pass
        try:
            del source
        except Exception:
            pass
        gc.collect()


def write_ota_pending(size, remote):
    payload = {
        "file": OTA_MAIN_FILE,
        "backup": OTA_BACKUP_FILE,
        "size": size,
        "remote": remote,
        "version": APP_VERSION,
        "ticks_ms": time.ticks_ms(),
    }
    with open(OTA_PENDING_FILE, "w") as f:
        f.write(json.dumps(payload))
    sync_filesystem()


def install_ota_upload(size, remote):
    main_moved = False
    try:
        remove_file(OTA_BACKUP_FILE)
        write_ota_pending(size, remote)
        os.rename(OTA_MAIN_FILE, OTA_BACKUP_FILE)
        main_moved = True
        os.rename(OTA_UPLOAD_FILE, OTA_MAIN_FILE)
        sync_filesystem()
    except Exception:
        if (
            main_moved
            and file_exists(OTA_BACKUP_FILE)
            and not file_exists(OTA_MAIN_FILE)
        ):
            try:
                os.rename(OTA_BACKUP_FILE, OTA_MAIN_FILE)
            except Exception:
                pass
        remove_file(OTA_PENDING_FILE)
        remove_file(OTA_BOOTING_FILE)
        sync_filesystem()
        raise


def clear_ota_markers_if_healthy():
    if not (file_exists(OTA_PENDING_FILE) or file_exists(OTA_BOOTING_FILE)):
        return
    remove_file(OTA_PENDING_FILE)
    remove_file(OTA_BOOTING_FILE)
    sync_filesystem()
    log("OTA boot accepted; HTTP server is listening")


def handle_ota_update(client, headers, initial_body, remote):
    if not OTA_ENABLED:
        response(client, 403, "text/plain; charset=utf-8", "OTA updates disabled\n")
        return

    remove_file(OTA_UPLOAD_FILE)
    try:
        log("OTA upload started from {}".format(remote))
        size = stream_request_body_to_file(
            client, headers, initial_body, OTA_UPLOAD_FILE, OTA_MAX_BYTES
        )
        validate_ota_upload(OTA_UPLOAD_FILE)
        install_ota_upload(size, remote)
    except ValueError as exc:
        remove_file(OTA_UPLOAD_FILE)
        log("OTA upload rejected from {}: {}".format(remote, exc))
        response(client, 400, "text/plain; charset=utf-8", "{}\n".format(exc))
        return
    except Exception as exc:
        remove_file(OTA_UPLOAD_FILE)
        log("OTA upload failed from {}: {}".format(remote, exc))
        raise

    log("OTA update installed from {}: {} bytes; rebooting".format(remote, size))
    json_response(client, {"ok": True, "size": size, "rebooting": True})
    sleep_with_watchdog(0.3)
    machine.reset()


def is_socket_timeout(exc):
    if isinstance(exc, OSError) and exc.args:
        return exc.args[0] in (11, 110, 116)
    return False


def read_request(client):
    method, path, headers, rest = read_request_start(client)
    if not method:
        return "", "", {}, b""
    return method, path, headers, read_request_body(client, headers, rest)


def send_all(client, data):
    view = memoryview(data)
    sent = 0
    while sent < len(view):
        feed_watchdog()
        n = client.send(view[sent:])
        if n == 0:
            raise RuntimeError("socket connection broken")
        sent += n
    feed_watchdog()


def response(client, code, content_type, body, headers=None):
    if isinstance(body, str):
        body = body.encode("utf-8")

    reason = {
        200: "OK",
        204: "No Content",
        400: "Bad Request",
        401: "Unauthorized",
        403: "Forbidden",
        404: "Not Found",
        405: "Method Not Allowed",
        500: "Internal Server Error",
    }.get(code, "OK")

    extra = ""
    if headers:
        for key, value in headers.items():
            extra += "{}: {}\r\n".format(key, value)

    head = (
        "HTTP/1.1 {} {}\r\n"
        "Content-Type: {}\r\n"
        "Content-Length: {}\r\n"
        "Cache-Control: no-store\r\n"
        "Connection: close\r\n"
        "{}\r\n"
    ).format(code, reason, content_type, len(body), extra)
    send_all(client, head.encode("utf-8"))
    if body:
        send_all(client, body)


def json_response(client, payload, code=200):
    response(client, code, "application/json; charset=utf-8", json.dumps(payload))


def is_client_disconnect(exc):
    if isinstance(exc, OSError) and exc.args:
        return exc.args[0] in (32, 103, 104, 110, 116)
    return False


def check_auth(headers):
    if not AUTH_ENABLED:
        return True
    auth = headers.get("authorization", "")
    if not auth.startswith("Basic "):
        return False
    try:
        decoded = binascii.a2b_base64(auth[6:]).decode()
        user, password = decoded.split(":", 1)
        return user == AUTH_USER and password == AUTH_PASS
    except Exception:
        return False


def unauthorized(client):
    response(
        client,
        401,
        "text/plain; charset=utf-8",
        "Unauthorized\n",
        {"WWW-Authenticate": 'Basic realm="OOB Management"'},
    )


def remote_label(remote_addr):
    if not remote_addr:
        return "unknown"
    try:
        return str(remote_addr[0])
    except Exception:
        return str(remote_addr)


def status_payload():
    ip, subnet, gateway, dns = get_ipv4_config(nic)
    return {
        "app": APP_NAME,
        "version": APP_VERSION,
        "hostname": HOSTNAME,
        "ip": ip,
        "subnet": subnet,
        "gateway": gateway,
        "dns": dns,
        "link": bool(nic and nic.isconnected()),
        "heap_free": gc.mem_free() if hasattr(gc, "mem_free") else None,
        "pcs": pc_status(),
    }


def html_escape(value):
    return (
        str(value)
        .replace("&", "&amp;")
        .replace("<", "&lt;")
        .replace(">", "&gt;")
        .replace('"', "&quot;")
    )
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

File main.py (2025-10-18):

from machine import Pin, I2C, UART
import network, socket, time, ujson, os, esp32, machine, ubinascii, gc

# ========= Meta =========
APP_VERSION = "OOB-Management 1.0.0"
BUILD_TIME  = "2025-10-11"

# ========= Optional hardcoded Wi-Fi =========
FORCE_WIFI_SSID = ""           # e.g. "MySSID"
FORCE_WIFI_PASS = ""           # e.g. "supersecret"
FORCE_WIFI_OVERWRITE_NVS = True

HEARTBEAT_LED_PIN = Pin(2, Pin.OUT)
ACTIVITY_LED_PIN  = Pin(1, Pin.OUT)

# ========= NVS =========
nvs = esp32.NVS("cfg")

def get_wifi_creds():
    """Return (ssid, psk) from NVS; ('', '') on any error or if missing."""
    try:
        ssid_buf = bytearray(32)
        psk_buf  = bytearray(64)
        l1 = nvs.get_blob("wifi_ssid", ssid_buf)
        l2 = nvs.get_blob("wifi_pass", psk_buf)
        return ssid_buf[:l1].decode(), psk_buf[:l2].decode()
    except Exception:
        return "", ""

def set_wifi_creds(ssid: str, psk: str):
    """Persist Wi-Fi creds to NVS and commit."""
    nvs.set_blob("wifi_ssid", ssid.encode())
    nvs.set_blob("wifi_pass", psk.encode())
    nvs.commit()

# Push hardcoded creds if asked to.
if FORCE_WIFI_OVERWRITE_NVS and FORCE_WIFI_SSID:
    try:
        set_wifi_creds(FORCE_WIFI_SSID, FORCE_WIFI_PASS or "")
    except Exception:
        pass  # allow AP fallback

# ========= Auth =========
AUTH_NVS = esp32.NVS("auth")
DEFAULT_USER = "oob"
DEFAULT_PASS = "oob"

def get_auth_creds():
    """Return (user, pass) from NVS or defaults."""
    try:
        buf_u = bytearray(32)
        buf_p = bytearray(32)
        lu = AUTH_NVS.get_blob("user", buf_u)
        lp = AUTH_NVS.get_blob("pass", buf_p)
        user = buf_u[:lu].decode() if lu else DEFAULT_USER
        pw   = buf_p[:lp].decode() if lp else DEFAULT_PASS
        return user, pw
    except Exception:
        return DEFAULT_USER, DEFAULT_PASS

def set_auth_creds(user, pw):
    AUTH_NVS.set_blob("user", user.encode())
    AUTH_NVS.set_blob("pass", pw.encode())
    AUTH_NVS.commit()

def check_basic_auth(headers):
    """Return True if Authorization header matches stored creds."""
    auth = headers.get("authorization", "")
    if not auth.startswith("Basic "):
        return False
    try:
        b64 = auth[6:]
        raw = ubinascii.a2b_base64(b64).decode()
        user, pw = raw.split(":", 1)
        stored_user, stored_pw = get_auth_creds()
        return user == stored_user and pw == stored_pw
    except Exception:
        return False

def send_unauth(cl):
    """Send 401 Unauthorized response."""
    try:
        cl.sendall(
            b"HTTP/1.1 401 Unauthorized\r\n"
            b"WWW-Authenticate: Basic realm=\"OOB\"\r\n"
            b"Content-Type: text/plain\r\n"
            b"Content-Length: 12\r\n\r\nUnauthorized"
        )
    except Exception:
        pass

# ==== Logging ====
LOG_BUF = []
LOG_BUF_MAX = 50

def log(msg):
    """Log message to console and buffer."""
    ts = str(time.ticks_ms())
    line = "[%s] %s" % (ts, msg)
    print(line)
    LOG_BUF.append(line)
    if len(LOG_BUF) > LOG_BUF_MAX:
        LOG_BUF.pop(0)

def get_log():
    """Return recent log lines as a string."""
    return "\n".join(LOG_BUF)

# ========= Wi-Fi bring-up & Setup AP =========
SETUP_MODE = False
ap = None
AP_ESSID = "OOB-Setup-XXXX"
AP_PASS  = "oobsetup1"  # >=8 chars

def start_ap():
    """Bring up a simple setup AP (WPA/WPA2)."""
    global ap, AP_ESSID
    ap = network.WLAN(network.AP_IF)
    ap.active(True)
    suffix = ubinascii.hexlify(machine.unique_id())[-4:].decode()
    AP_ESSID = "OOB-Setup-" + suffix
    ap.config(
        essid=AP_ESSID,
        password=AP_PASS,
        authmode=network.AUTH_WPA_WPA2_PSK,
        channel=6,
    )
    try:
        log("AP up: %s" % str(ap.ifconfig()))
    except Exception as e:
        log("AP up error: %s" % e)

def bringup_wifi():
    """Connect STA using saved creds; on missing creds enable setup AP. Return WLAN or None."""
    global SETUP_MODE
    ssid, psk = get_wifi_creds()
    if not ssid:
        SETUP_MODE = True
        start_ap()
        return None

    wlan = network.WLAN(network.STA_IF)
    wlan.active(True)
    if not wlan.isconnected():
        try:
            log("Connecting to Wi-Fi SSID: %s" % ssid)
            wlan.connect(ssid, psk)
            # Wait ~20s for association
            for _ in range(80):
                if wlan.isconnected():
                    break
                time.sleep(0.25)
        except Exception as e:
            log("Wi-Fi connect error: %s" % e)

    log("IP: %s" % (wlan.ifconfig()[0] if wlan.isconnected() else "No WiFi"))
    return wlan

wlan = bringup_wifi()

# ========= Small utils =========
def _mac_str(b):
    """Return MAC bytes as 'AA:BB:CC:DD:EE:FF' string; 'NA' on error."""
    try:
        return ":".join("{:02X}".format(x) for x in b)
    except Exception:
        return "NA"

def fs_stats_mb():
    """Return (total_mb, free_mb) for '/' FS; (None, None) on error."""
    try:
        s = os.statvfs("/")
        bs = s[0]
        total = (s[2] * bs) / (1024 * 1024)
        free  = (s[3] * bs) / (1024 * 1024)
        return round(total, 1), round(free, 1)
    except Exception:
        return None, None

def get_hostname():
    """Return configured hostname if available; else NVS 'hostname' or ''."""
    try:
        return network.hostname()
    except Exception:
        try:
            return nvs.get_str("hostname")
        except Exception:
            return ""

def wifi_rssi(w):
    """Return RSSI from WLAN or None if not available."""
    try:
        return w.status("rssi")
    except Exception:
        return None
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

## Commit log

2025-10-11 add wiring drawings
2026-05-02 add v2
    [atx_power_control_2.0.kicad_pcb, atx_power_control_2.0.kicad_sch, atx_power_control_bravo_2.0.kicad_pcb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]
